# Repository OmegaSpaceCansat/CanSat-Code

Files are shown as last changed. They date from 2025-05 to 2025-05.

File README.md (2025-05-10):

# 🛰️ Omega Space - CanSat 2025

¡Bienvenidos al repositorio oficial del proyecto **Omega Space CanSat 2025**! Este proyecto ha sido desarrollado por estudiantes de secundaria de la Región de Murcia (España) con el objetivo de diseñar y construir un mini satélite funcional con fines de rescate y reconocimiento.
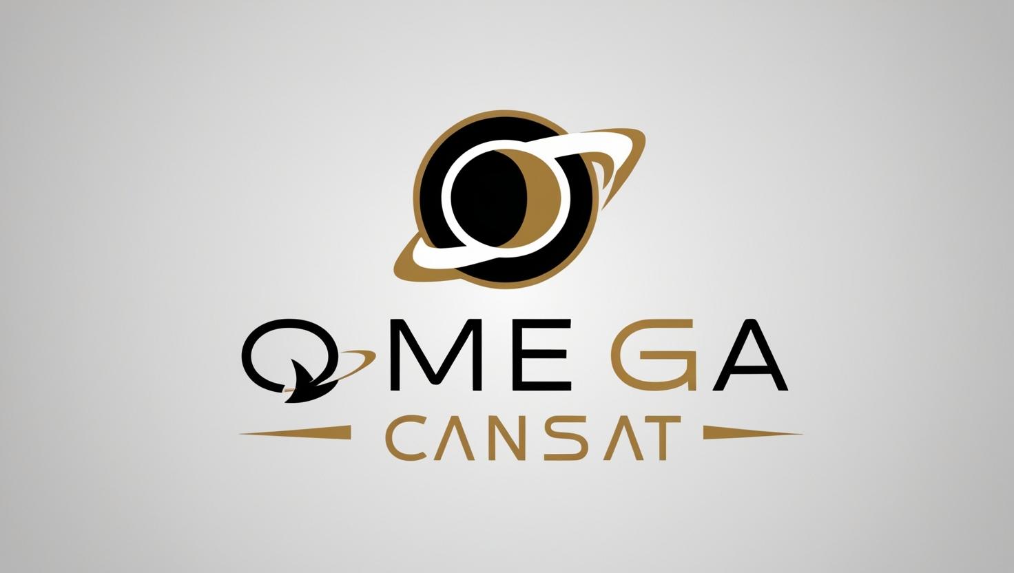
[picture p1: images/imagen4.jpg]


## 🎯 Objetivo de la Misión

El CanSat está diseñado como una herramienta autónoma de reconocimiento en situaciones de emergencia. Su misión principal es mejorar la capacidad de localización y seguridad en entornos de difícil acceso.

### Funcionalidades principales

- 🔥 **Cámara térmica AMG8833** para detectar fuentes de calor en condiciones de baja visibilidad.
- 📡 **Sistema FPV** para visualización en tiempo real durante la misión.
- 🪂 **Paracaídas dirigible con control activo**, que permite un descenso estable y guiado.

## 🧠 Proyecto Científico

Buscamos demostrar cómo la tecnología aeroespacial puede ayudar en labores humanitarias. Nuestro CanSat incorpora tecnologías avanzadas para:

- Detección térmica en zonas de rescate.
- Orientación automática mediante acelerómetro y controladores de motor.
- Localización GPS en tiempo real.
- Transmisión de datos a la Estación de Tierra usando APC220.

## 🧩 Componentes Técnicos

| Componente | Función |
|---|---|
| **Arduino Nano** | CPU principal del sistema |
| **Cámara térmica AMG8833** | Identificación de fuentes de calor |
| **Sensor BMP280** | Altitud, presión y temperatura ambiental |
| **MPU6050** | Detección de orientación e inclinación |
| **GPS BN-220** | Geolocalización precisa |
| **APC220** | Comunicación con la estación de tierra |
| **Cámara FPV** | Streaming de vídeo en vivo |
| **Motor DC + L298N Mini** | Control del paracaídas durante el descenso |

## ⚙️ Diseño y Fabricación

- Diseño estructural impreso en 3D, optimizado para cámaras y cuerdas del paracaídas.
- Paracaídas de tipo parapente (rectangular) para mayor estabilidad.
- Sistema de **estabilización activa** con motores que corrigen la inclinación detectada por el MPU6050.

## 🛰️ Estación de Tierra

Utilizamos **Serial Studio**, una herramienta multiplataforma para visualizar en tiempo real los datos enviados por el CanSat. La estación se compone de:

- Ordenador portátil con Serial Studio
- Arduino Nano conectado a un módulo APC220
- Antena Yagi para maximizar la recepción de señal

## 🗓️ Planificación

Nuestro trabajo se ha dividido en 3 fases principales:
1. **Diseño y planificación** (noviembre)
2. **Desarrollo del CanSat y estación de tierra** (diciembre-febrero)
3. **Pruebas y validación** (marzo)

Total: más de 50 horas de trabajo colaborativo documentado.

## 👥 Organización del equipo

El equipo está dividido en cuatro subgrupos:

- **Tierra**: interfaz de la estación y visualización de datos.
- **Aire**: programación y comunicaciones del satélite.
- **Diseño**: estructura y ensamblaje físico.
- **Comunicaciones**: documentación, difusión y gestión del repositorio.

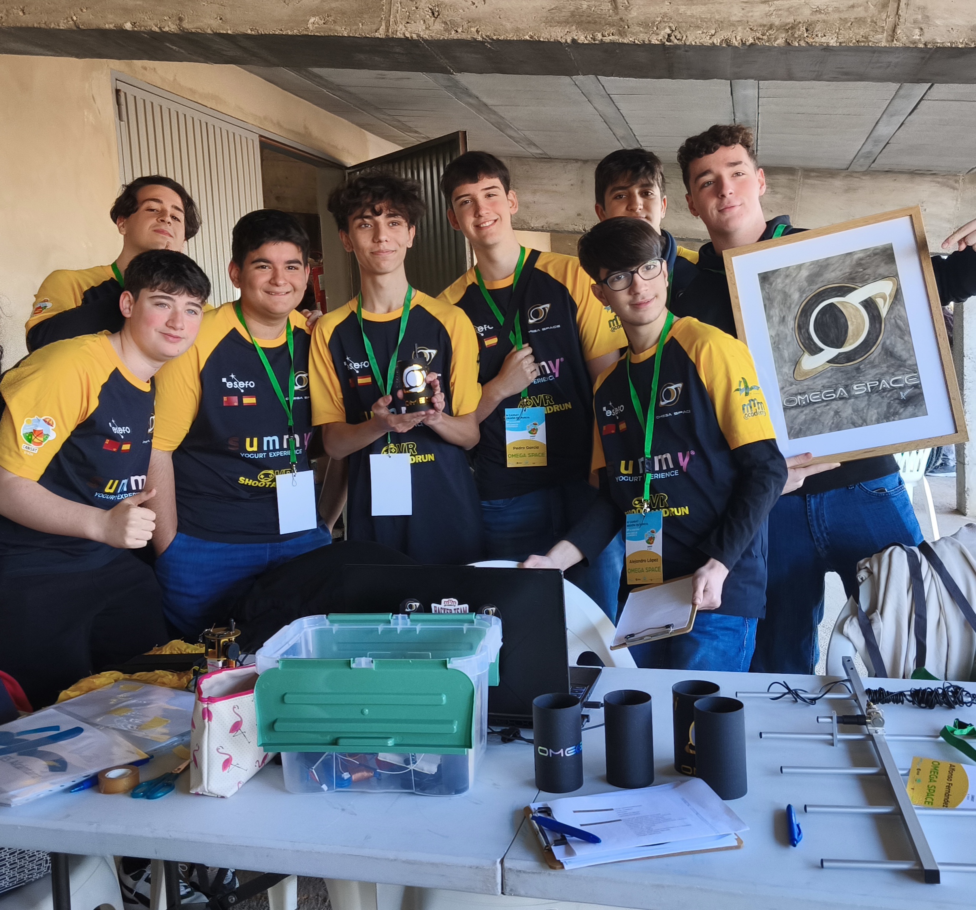
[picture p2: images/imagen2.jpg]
Imagen del equipo


## 📢 Difusión y Patrocinio

Estamos comprometidos con la visibilidad del proyecto y la divulgación científica. Contamos con redes sociales activas y un programa de patrocinio basado en:

- Visibilidad de marca
- Apoyo a la educación STEM
- Acceso a talento joven

Síguenos en nuestras redes:
- Instagram: [@omegaspace.cansat](https://instagram.com/omegaspace.cansat)
- Twitter: [@SpaceOmega84376](https://twitter.com/SpaceOmega84376)

---

© 2025 - Omega Space Team  
Mentores: José Ángel Martínez  
Colaboradores: IES Alcántara · MMMacademy

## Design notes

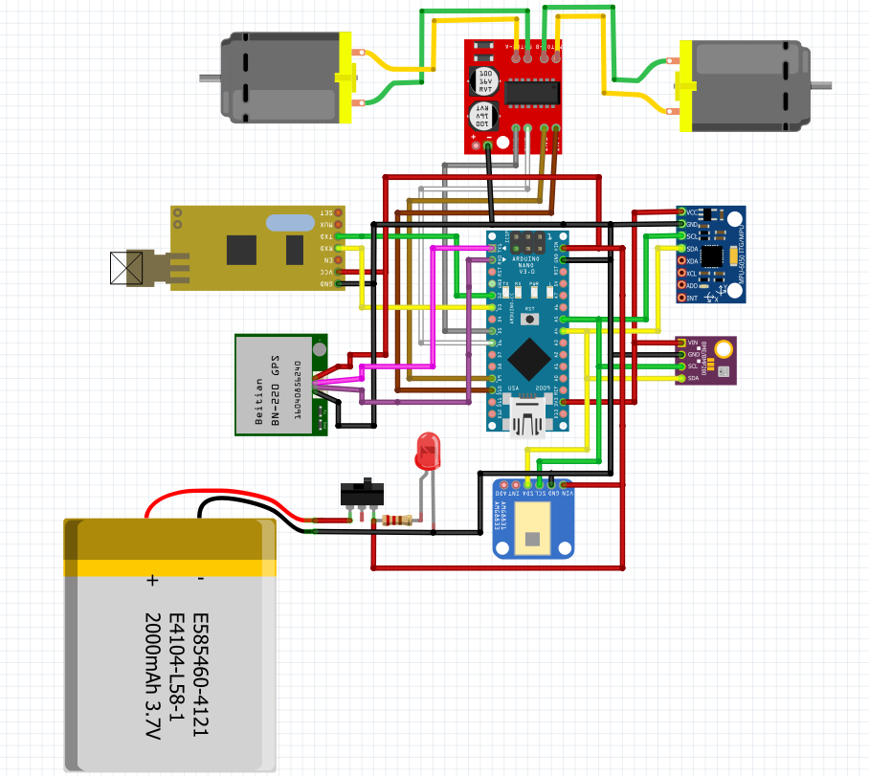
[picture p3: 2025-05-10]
images/Imagen5.png

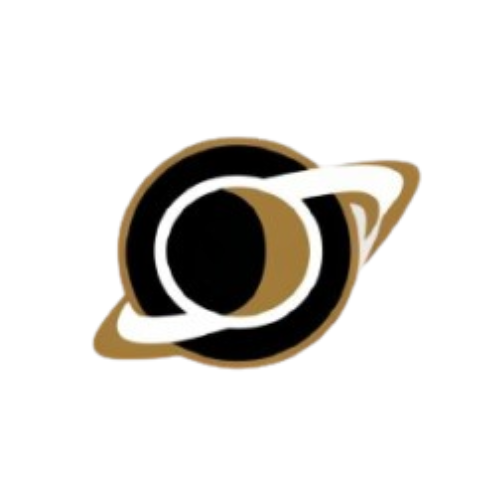
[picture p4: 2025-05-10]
images/imagen3.png

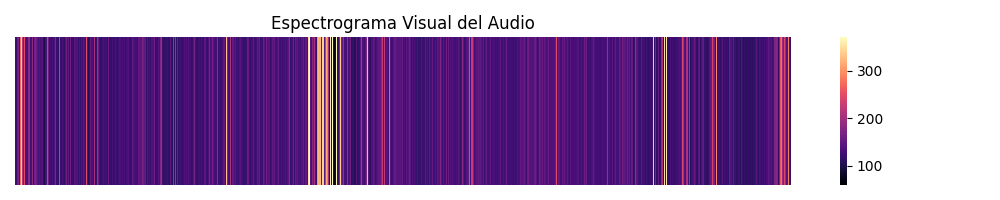
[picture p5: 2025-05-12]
Codigos python/audio_heatmap.png

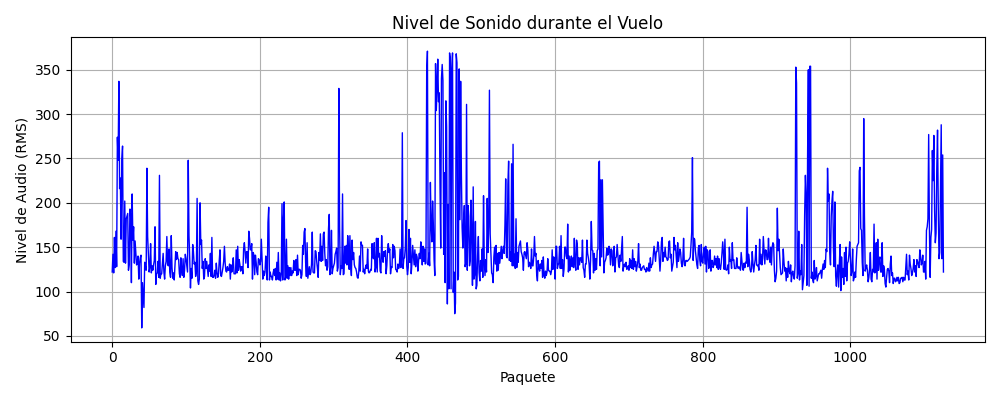
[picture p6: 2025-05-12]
Codigos python/audio_linea.png

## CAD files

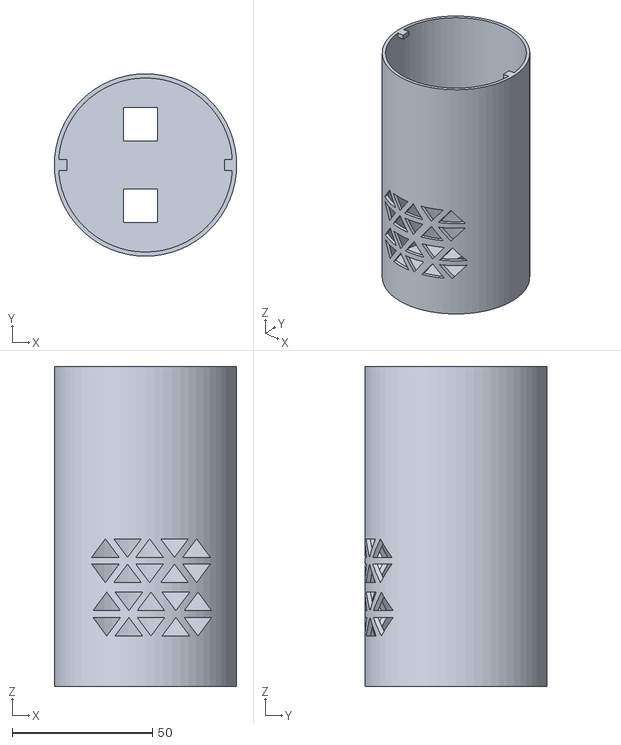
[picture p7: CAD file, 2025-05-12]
diseños3D/carcasaomegagalicia.stl
65.0 x 65.0 x 114.0

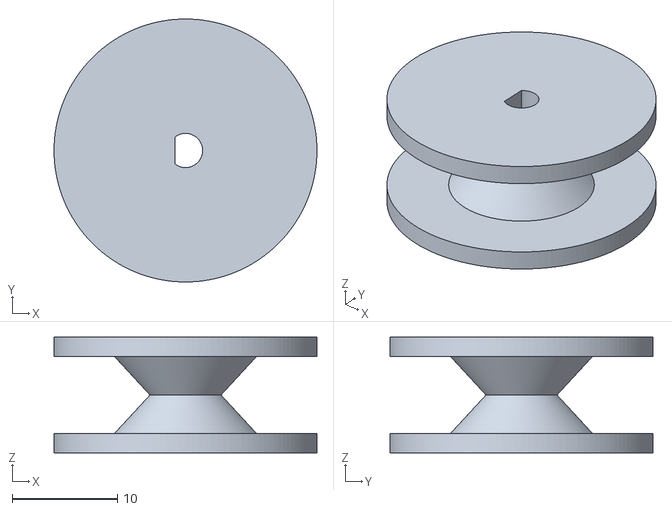
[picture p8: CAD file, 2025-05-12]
diseños3D/ruedaomega25.stl
25.0 x 25.0 x 11.0

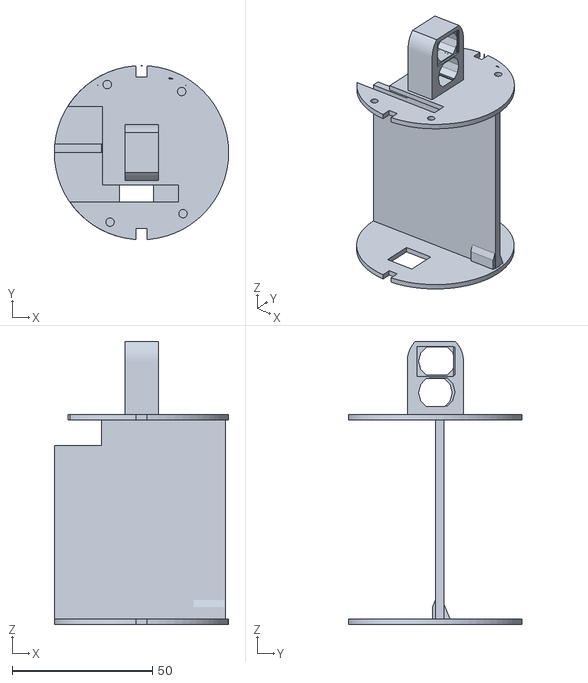
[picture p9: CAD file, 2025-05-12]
diseños3D/interioromega.stl
62.1 x 61.9 x 100.8

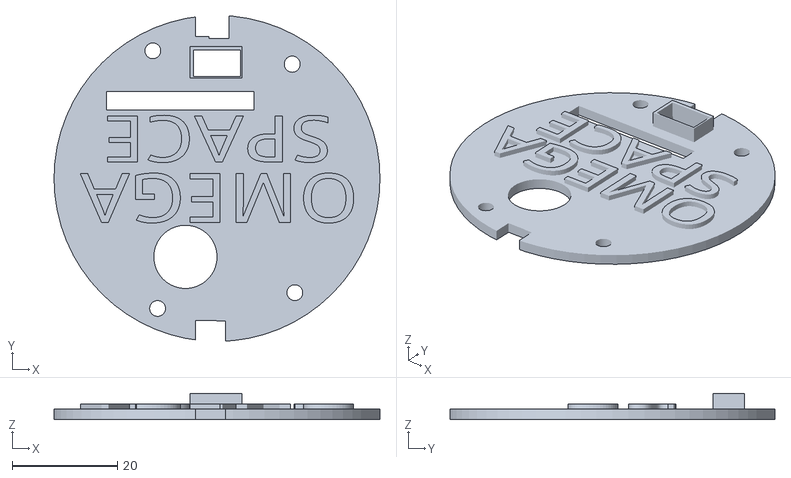
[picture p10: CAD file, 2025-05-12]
diseños3D/tapaomegac.stl
62.0 x 61.8 x 5.00

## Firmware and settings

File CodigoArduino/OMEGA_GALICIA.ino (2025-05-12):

// Omega Space - CanSat Fase Nacional
// Código principal de vuelo: adquisición de datos, control de motores, almacenamiento y transmisión
// Sensores: BME280 (clima), ICM20948 (IMU), GPS PA1010D (I2C), MAX9814 (micrófono), microSD
// Autores: Equipo Omega Space - IES Alcántara - Región de Murcia

#include <Wire.h>
#include <Adafruit_Sensor.h>
#include <Adafruit_BME280.h>
#include <Adafruit_ICM20948.h>
#include <Adafruit_GPS.h>
#include <SPI.h>
#include <SD.h>

// Constantes del entorno
#define SEALEVELPRESSURE_HPA 1013.25  // Presión a nivel del mar

// Pines del sistema
#define SD_CS 8             // Chip Select de la microSD
#define AUDIO_PIN A0        // Entrada analógica del micrófono
#define NUM_MUESTRAS 100    // Muestras para el cálculo de nivel sonoro

// Pines del controlador de motores (L298N)
#define MOTOR_A_IN1 5
#define MOTOR_A_IN2 6
#define MOTOR_B_IN1 9
#define MOTOR_B_IN2 10
#define VELOCIDAD_MOTOR 60      // PWM de motor
#define ANGULO_UMBRAL 35        // Umbral de corrección en grados

// Objetos de sensores
Adafruit_BME280 bme;
Adafruit_ICM20948 icm;
sensors_event_t accel, gyro, temp_event;
Adafruit_GPS gps(&Wire);  // GPS por I2C

// Variables de estado
int paquete = 0;
float altitudAnterior = 0;
float ay_offset = 0;
float az_offset = 0;

void setup() {
  Serial.begin(115200);
  Serial1.begin(9600);        // Comunicación con APC220
  Wire.begin();

  pinMode(LED_BUILTIN, OUTPUT);  // LED de actividad

  // Inicialización de sensores
  if (!bme.begin(0x76)) while (1);
  if (!icm.begin_I2C()) while (1);
  if (!gps.begin(0x60)) while (1);

  gps.sendCommand(PMTK_SET_NMEA_OUTPUT_RMCGGA);
  gps.sendCommand(PMTK_SET_NMEA_UPDATE_1HZ);
  gps.sendCommand(PGCMD_ANTENNA);

  if (!SD.begin(SD_CS)) while (1);

  File file = SD.open("datos.csv", FILE_WRITE);
  if (file && file.size() == 0) {
    file.println("Etiqueta,Temp,Presion,Humedad,Alt_BME,Lat,Lon,Alt_GPS,Ax,Ay,Az,Gx,Gy,Gz,NivelAudio,Paquete");
    file.close();
  }

  // Pines de motores
  pinMode(MOTOR_A_IN1, OUTPUT);
  pinMode(MOTOR_A_IN2, OUTPUT);
  pinMode(MOTOR_B_IN1, OUTPUT);
  pinMode(MOTOR_B_IN2, OUTPUT);

  // Calibración de inclinación inicial
  icm.getEvent(&accel, &gyro, &temp_event);
  ay_offset = accel.acceleration.y;
  az_offset = accel.acceleration.z;
}

void loop() {
  // Sensor BME280
  float temp_bme = bme.readTemperature();
  float pres = bme.readPressure() / 100.0F;
  float alt_bme = bme.readAltitude(SEALEVELPRESSURE_HPA);
  float humedad = bme.readHumidity();

  // Detección de descenso
  bool descendiendo = (alt_bme < altitudAnterior);
  altitudAnterior = alt_bme;

  // IMU (ICM20948)
  icm.getEvent(&accel, &gyro, &temp_event);
  float ax = accel.acceleration.x;
  float ay = accel.acceleration.y;
  float az = accel.acceleration.z;
  float gx = gyro.gyro.x;
  float gy = gyro.gyro.y;
  float gz = gyro.gyro.z;

  // Corrección de inclinación inicial
  float ay_corr = ay - ay_offset;
  float az_corr = az - az_offset;
  float roll = atan2(ay_corr, az_corr) * 180.0 / PI;

  // GPS
  for (int i = 0; i < 10; i++) {
    char c = gps.read();
    if (gps.newNMEAreceived()) gps.parse(gps.lastNMEA());
  }
  float lat = gps.fix ? gps.latitude : 0.0;
  float lon = gps.fix ? gps.longitude : 0.0;
  float alt_gps = gps.fix ? gps.altitude : 0.0;

  // Nivel de audio
  int nivelAudio = capturarNivelAudio();

  // Construcción de trama
  String trama = "Omega," +
                 String(temp_bme, 2) + "," + String(pres, 2) + "," + String(humedad, 2) + "," + String(alt_bme, 2) + "," +
                 String(lat, 6) + "," + String(lon, 6) + "," + String(alt_gps, 2) + "," +
                 String(ax, 4) + "," + String(ay, 4) + "," + String(az, 4) + "," +
                 String(gx, 4) + "," + String(gy, 4) + "," + String(gz, 4) + "," +
                 String(nivelAudio) + "," + String(paquete);

  Serial.println(trama);
  Serial1.println(trama);

  // LED de confirmación
  digitalWrite(LED_BUILTIN, HIGH);
  delay(50);
  digitalWrite(LED_BUILTIN, LOW);

  // Guardado en microSD
  File file = SD.open("datos.csv", FILE_WRITE);
  if (file) {
    file.println(trama);
    file.close();
  }

  // Activar motores solo si está descendiendo y a más de 100 m
  if (descendiendo && alt_bme > 100.0) {
    if (roll > ANGULO_UMBRAL) ajustarMotores(true);
    else if (roll < -ANGULO_UMBRAL) ajustarMotores(false);
    else detenerMotores();
  } else {
    detenerMotores();
  }

  paquete++;
  delay(500);
}

int capturarNivelAudio() {
  long suma = 0;
  for (int i = 0; i < NUM_MUESTRAS; i++) {
    int lectura = analogRead(AUDIO_PIN) - 512;
    suma += lectura * lectura;
    delayMicroseconds(200);
  }
  return sqrt(suma / NUM_MUESTRAS);
}

void ajustarMotores(bool corregirDerecha) {
  if (corregirDerecha) {
    analogWrite(MOTOR_A_IN1, VELOCIDAD_MOTOR);
    digitalWrite(MOTOR_A_IN2, LOW);
    digitalWrite(MOTOR_B_IN1, LOW);
    analogWrite(MOTOR_B_IN2, VELOCIDAD_MOTOR);
  } else {
    digitalWrite(MOTOR_A_IN1, LOW);
    analogWrite(MOTOR_A_IN2, VELOCIDAD_MOTOR);
    analogWrite(MOTOR_B_IN1, VELOCIDAD_MOTOR);
    digitalWrite(MOTOR_B_IN2, LOW);
  }
}

void detenerMotores() {
  digitalWrite(MOTOR_A_IN1, LOW);
  digitalWrite(MOTOR_A_IN2, LOW);
  digitalWrite(MOTOR_B_IN1, LOW);
  digitalWrite(MOTOR_B_IN2, LOW);
}

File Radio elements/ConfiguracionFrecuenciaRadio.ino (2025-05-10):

/*
 Programa configuración APC220
 Fuente: https://github.com/inopya/APC220_Transceiver 

 Esquema de conexión módulo APC220 con Arduino

 ARDUINO    APC220
 GND   --->  GND
 13    --->  VCC
 12    --->  EN
 11    --->  RXD
 10    --->  TXD
  9    --->  AUX
  8    --->  SET

/*
 
 Cuando se lee la configuracion del modulo se obtiene un linea similar a esta: PARAM 415370 2 9 3 0 

  "PARAM AAAAAA B C D E"

  AAAAAA, es la frecuencia de trabajo del modulo expresada en KHz, Puede oscilar entre 418MHz y 455MHz
  - en el ejemplo 415.370 MHz 

  B, es la velocidad de transmision de radio frecuencia puede tomar los siguientes valores
  1 (2400bps), 2 (4800bps), 3 (9600bps), 4 (19200bps)
  
  C, es la potencia de emision, puede tomar valores entre 0 y 9, siendo 9 la mayor potencia
  
  D, velodidad de transferencia entre el modulo y arduino o PC  , toma valores  entre 0 y 6: 0 (1200bps), 1 (2400bps), 2 (4800bps),3 (9600bps), 4 (19200bps),  5 (38400bps), 6 (57600bps)
  - en el ejemplo 9600bps
  
  E, es el control de paridad de la informacion emitida por RF
  0 (sin control de paridad), 1 (paridad par), 2 (paridad impar)
  - sin control de paridad

  Para grabar informacion se ha de enviar una linea similar...
  WR 434000 3 9 3 0

  Esta configuracion seria: Frecuencia de emision 434MHz, velocidad RF 9600, 
  maxima potencia, Puerto serie 9600 y sin control de paridad
 
*/

#define __VERSION__ "\Configuracion del modulo RF433  APC220 v1.0\n"

//Librerias
#include <SoftwareSerial.h>

//Declaracion de constantes
#define SET      8
#define AUX      9
#define TXD     11
#define RXD     10
#define EN      12 
#define VCC     13
#define GND    GND

//definimos el puerto serie Software para comunicar con el modulo RF
SoftwareSerial APCport(RXD, TXD);  

void setup() 
{
  Serial.begin(9600);
  Serial.println(F(__VERSION__));

//iniciar el puerto serie software para comunicar con el APC220 
  APCport.begin(9600);    
  
  pinMode(SET,OUTPUT);
  pinMode(AUX,INPUT);
  pinMode(EN,OUTPUT);
  pinMode(VCC,OUTPUT);

  digitalWrite(SET,HIGH);
  digitalWrite(VCC,HIGH);
  digitalWrite(EN,HIGH);
  
  delay(1000);

  write_config();
  delay(1000);
  
  read_config();
  delay(5000);
}

void loop() 
{
  //no hacemos nada en esta seccion
}

// ESCRIBIR CONFIGURACION

void write_config()
{
  Serial.println(F("ESTABLECIENDO NUEVA CONFIGURACION...\n"));
  digitalWrite(SET, LOW);               // poner en modo configuracion
  delay(50);

//Parametros de configuración
  APCport.print("WR 420000 3 9 3 0");   
  APCport.write(0x0D);                  
  APCport.write(0x0A);                  
  delay(100);
  digitalWrite(SET, HIGH);              
}

// LEER CONFIGURACION

void read_config() 
{
  Serial.println(F("CONFIGURACION ACTUAL:\n"));
  digitalWrite(SET, LOW);         // poner en modo configuracion
  delay(50);                      // pausa para estabilizar
  APCport.print("RD");            // peticion de datos
  APCport.write(0x0D);            // fin de linea
  APCport.write(0x0A);            
  delay(100);                     // pausa para estabilizar
  
  while (APCport.available()) {
    Serial.write(APCport.read()); 
  }
  digitalWrite(SET, HIGH);        // volver al modo normal
}

//Fin del programa

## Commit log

2025-05-10 Mas cambios
    [OMEGA FRITZING.fzz]
2025-05-12 Simulador de vuelo
    Añadido simulador de vuelo y eso
    [Datos Omega Original.csv]
